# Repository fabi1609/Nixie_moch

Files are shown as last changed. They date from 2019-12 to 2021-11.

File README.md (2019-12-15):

# Nixie_moch

You are not permitted to use this design commercially.
This work is licensed under a Attribution-NonCommercial-ShareAlike 4.0 International (CC BY-NC-SA 4.0) License.



## Description

This is a tiny IN-12 Nixie clock based on STM32. Every SMD component is placed on the bottom side of the PCB. Hardware works with 5 V USB power supply. Boost converter is regulated and driven by STM32.
This project is in beta phase.

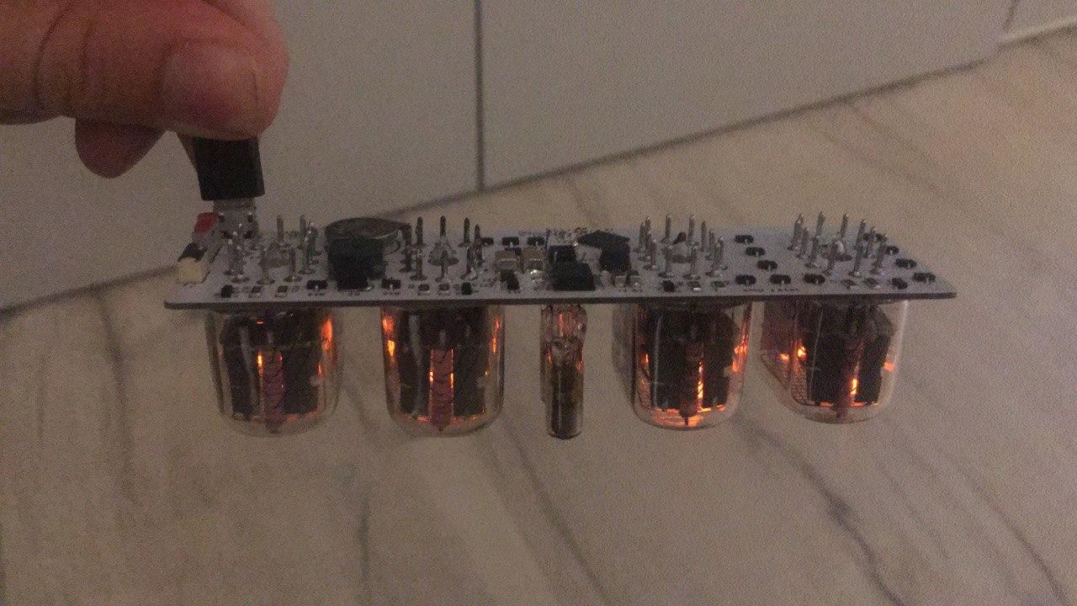
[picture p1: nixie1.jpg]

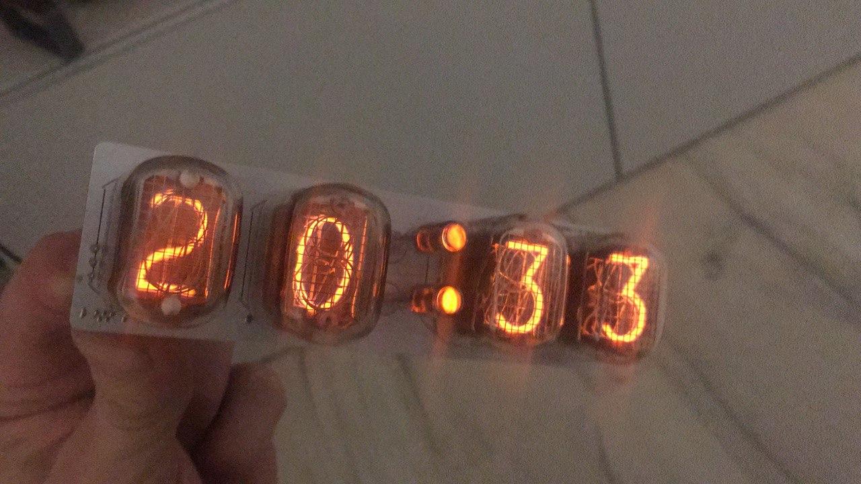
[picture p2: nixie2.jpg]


## TODO: Write explanation

You are not permitted to use this design commercially.
This work is licensed under a Attribution-NonCommercial-ShareAlike 4.0 International (CC BY-NC-SA 4.0) License.



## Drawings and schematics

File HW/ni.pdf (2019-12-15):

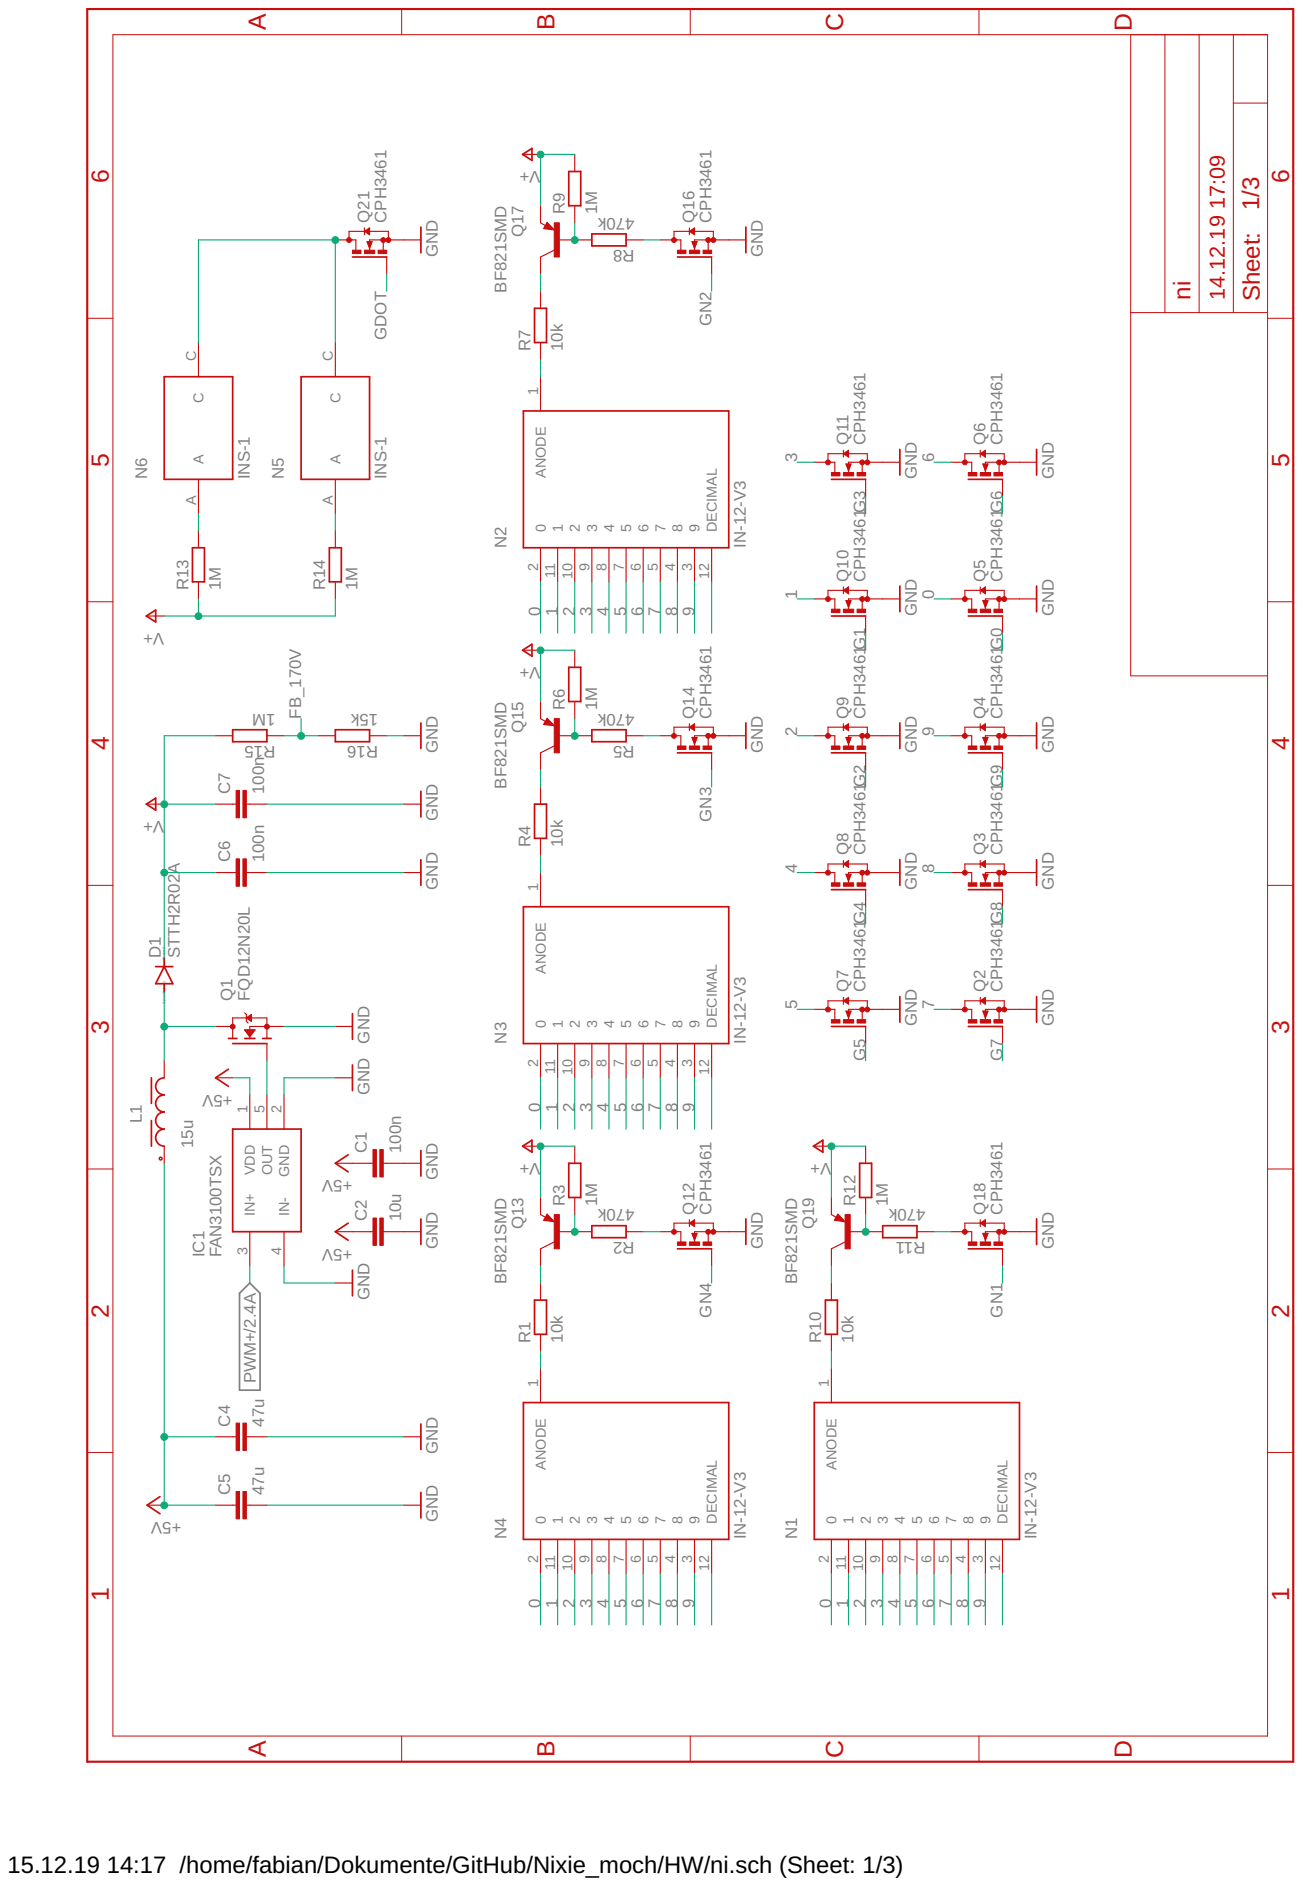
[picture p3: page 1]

GND GND GND GND GND

15.12.19 14:17 /home/fabian/Dokumente/GitHub/Nixie_moch/HW/ni.sch (Sheet: 1/3)

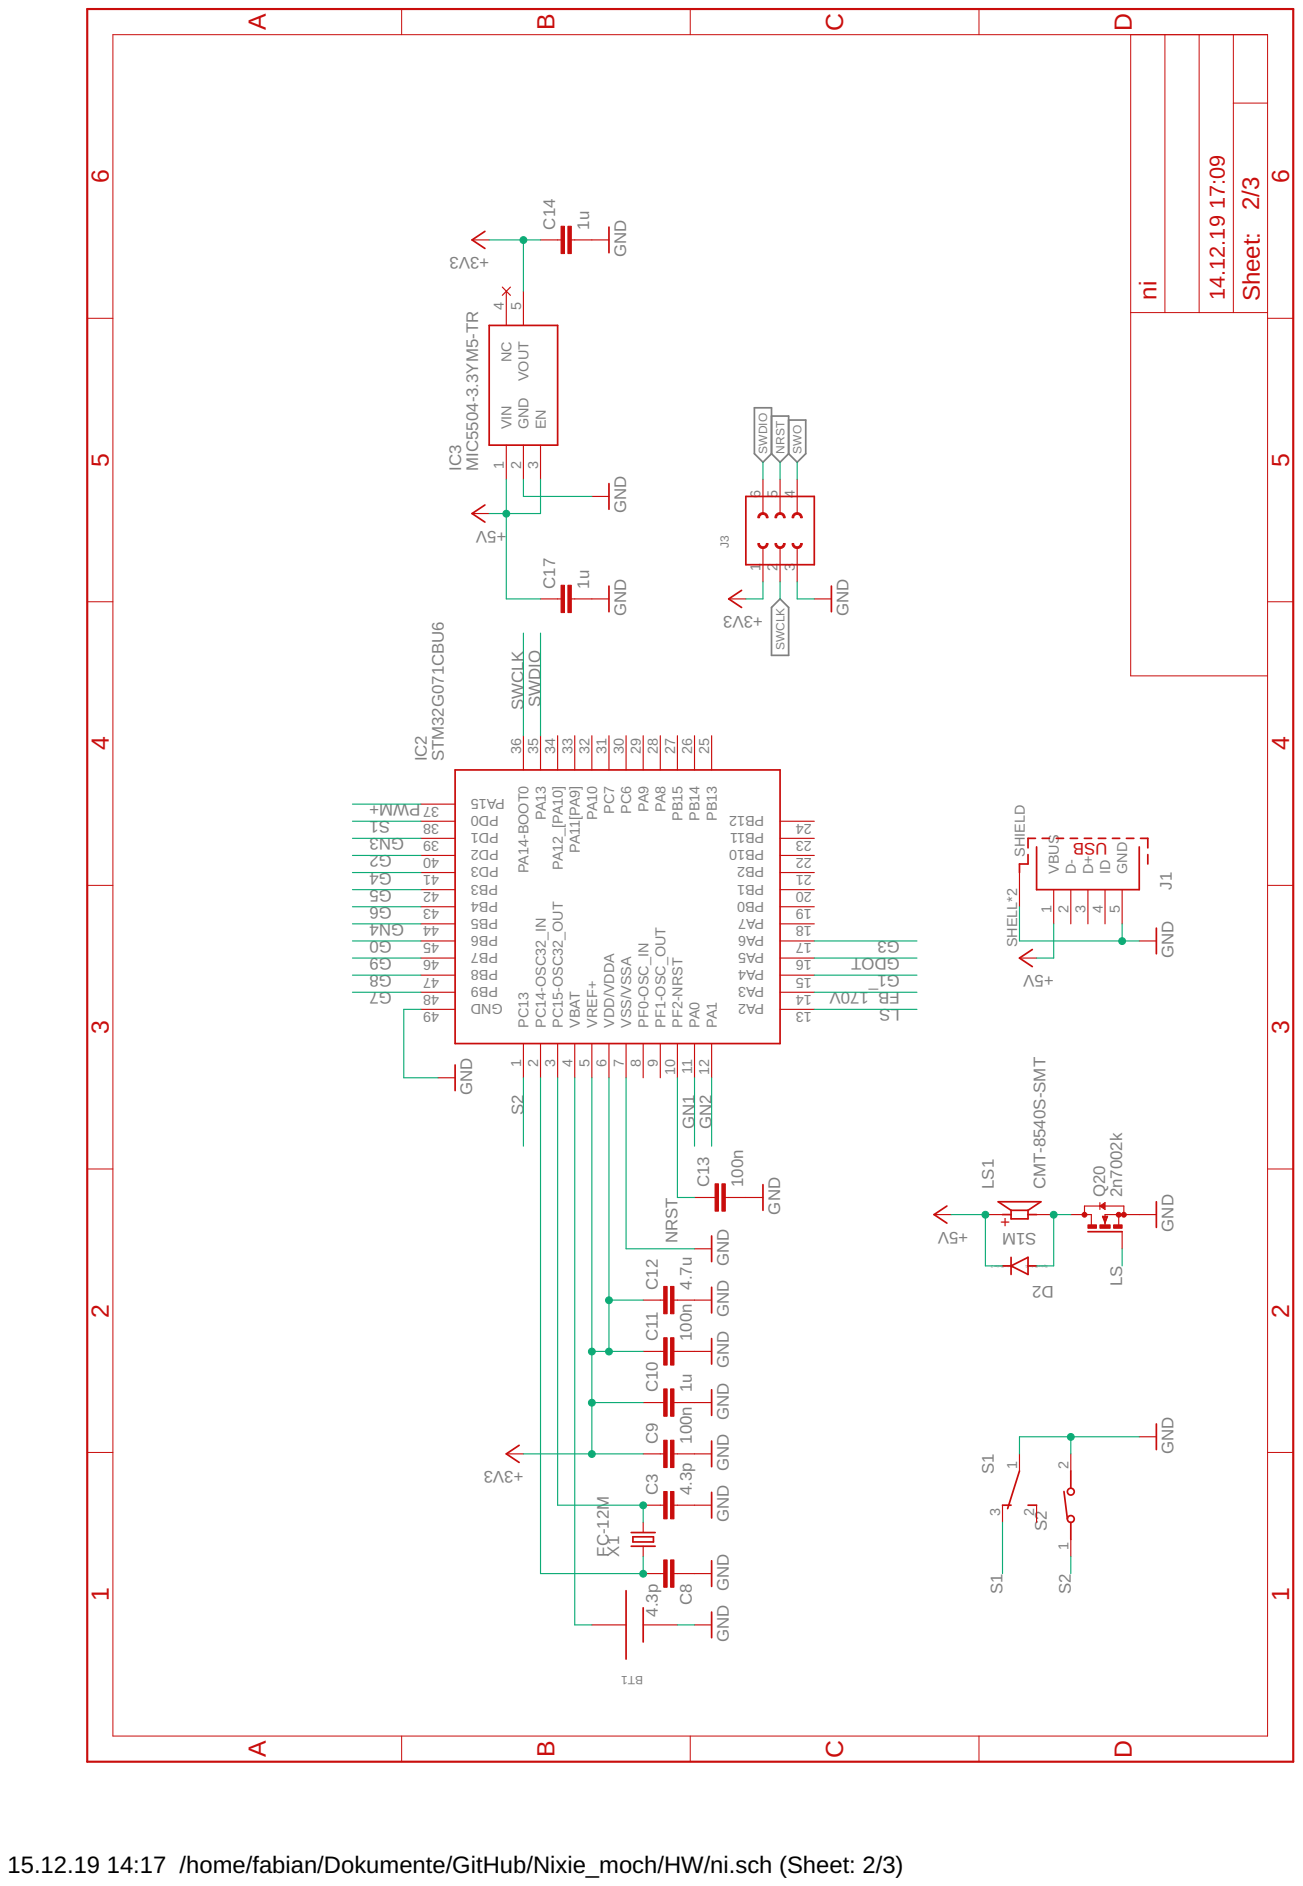
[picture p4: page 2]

15.12.19 14:17 /home/fabian/Dokumente/GitHub/Nixie_moch/HW/ni.sch (Sheet: 2/3)

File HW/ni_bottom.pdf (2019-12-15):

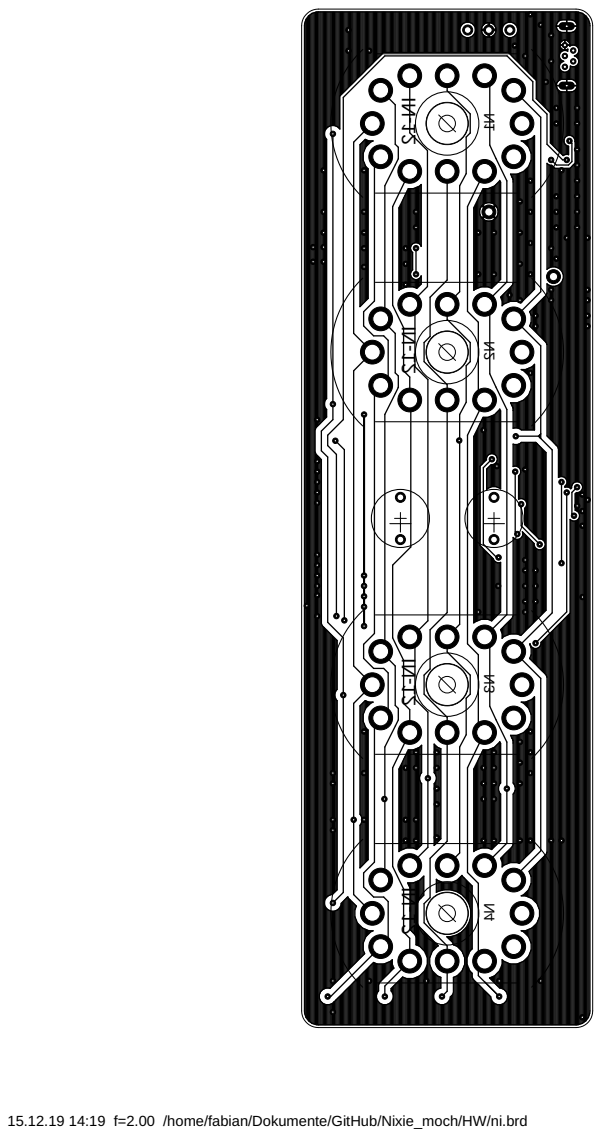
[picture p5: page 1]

15.12.19 14:19 f=2.00 /home/fabian/Dokumente/GitHub/Nixie_moch/HW/ni.brd

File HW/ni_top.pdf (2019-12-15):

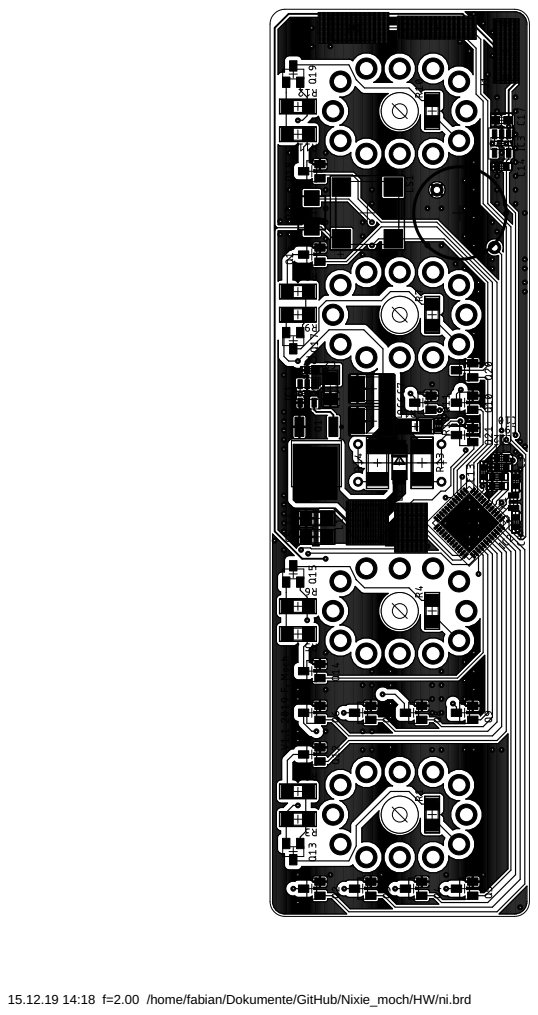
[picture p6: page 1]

15.12.19 14:18 f=2.00 /home/fabian/Dokumente/GitHub/Nixie_moch/HW/ni.brd

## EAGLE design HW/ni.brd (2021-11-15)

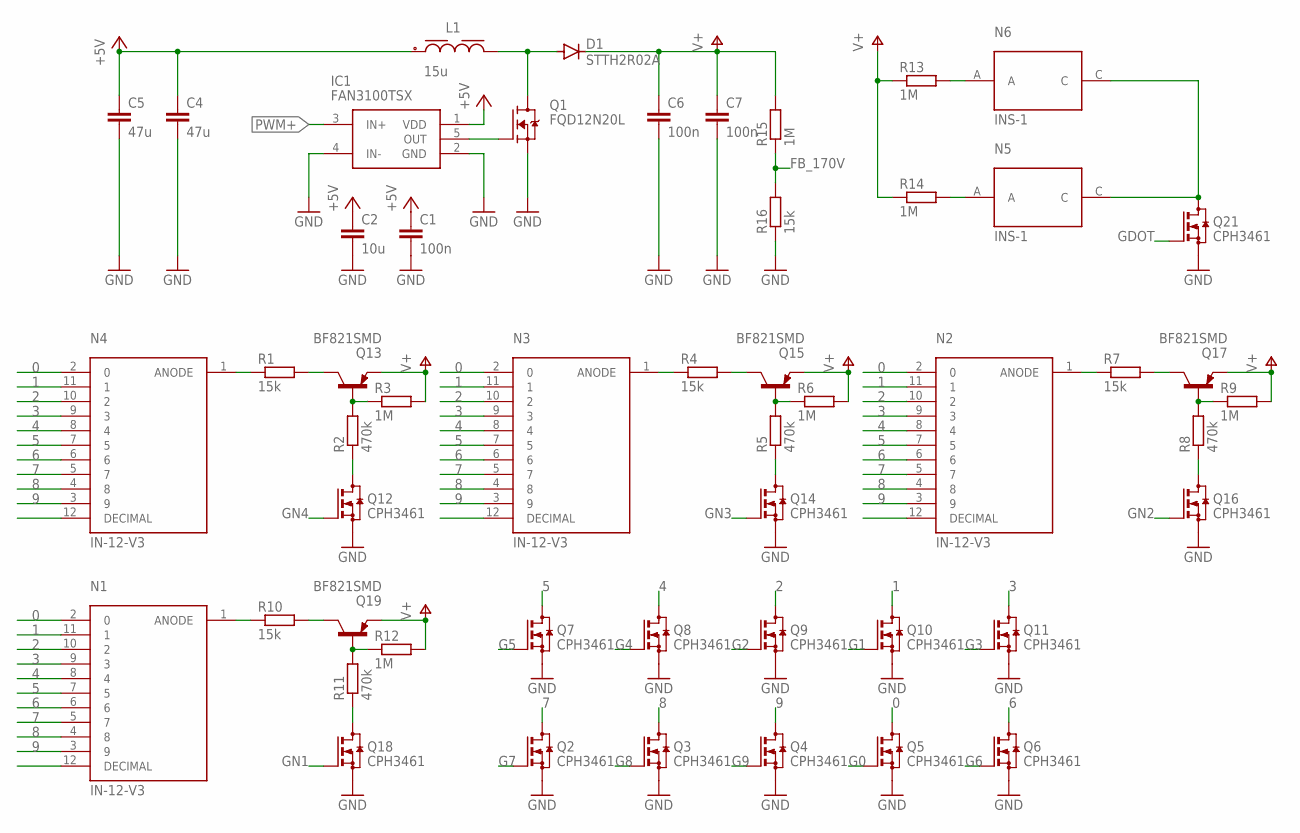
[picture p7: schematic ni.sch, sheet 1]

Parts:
C1: 100n; C0402
C2: 10u; C1206
C4, C5: 47u; C1206
C6, C7: 100n; C1812
D1: STTH2R02A; DO214AC
IC1: FAN3100TSX; SOT95P280X145-5N
L1: 15u; WE-LQS_5040
N1, N2, N3, N4: IN-12-V3; IN-12
N5, N6: INS-1
Q1: FQD12N20L; TO229P990X240-3N
Q2, Q3, Q4, Q5, Q6, Q7, Q8, Q9, Q10, Q11, Q12, Q14, Q16, Q18, Q21: CPH3461; SOT23
Q13, Q15, Q17, Q19: BF821SMD; SOT23-BEC
R1, R4, R7, R10: 15k; R1206
R2, R5, R8, R11: 470k; R1206
R3, R6, R9, R12, R15: 1M; R1206
R13, R14: 1M; R2010
R16: 15k; R0402

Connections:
0: N1.2 (0), N2.2 (0), N3.2 (0), N4.2 (0), Q5.3 (D)
1: N1.11 (1), N2.11 (1), N3.11 (1), N4.11 (1), Q10.3 (D)
2: N1.10 (2), N2.10 (2), N3.10 (2), N4.10 (2), Q9.3 (D)
3: N1.9 (3), N2.9 (3), N3.9 (3), N4.9 (3), Q11.3 (D)
4: N1.8 (4), N2.8 (4), N3.8 (4), N4.8 (4), Q8.3 (D)
5: N1.7 (5), N2.7 (5), N3.7 (5), N4.7 (5), Q7.3 (D)
6: N1.6, N2.6, N3.6, N4.6, Q6.3 (D)
7: N1.5 (7), N2.5 (7), N3.5 (7), N4.5 (7), Q2.3 (D)
8: N1.4 (8), N2.4 (8), N3.4 (8), N4.4 (8), Q3.3 (D)
9: N1.3 (9), N2.3 (9), N3.3 (9), N4.3 (9), Q4.3 (D)
+5V: C1.1, C2.1, C4.1, C5.1, IC1.1 (VDD), L1.1; also elsewhere on the board
FB_170V: R15.1, R16.2; also elsewhere on the board
G0: Q5.1 (G); also elsewhere on the board
G1: Q10.1 (G); also elsewhere on the board
G2: Q9.1 (G); also elsewhere on the board
G3: Q11.1 (G); also elsewhere on the board
G4: Q8.1 (G); also elsewhere on the board
G5: Q7.1 (G); also elsewhere on the board
G6: Q6.1 (G); also elsewhere on the board
G7: Q2.1 (G); also elsewhere on the board
G8: Q3.1 (G); also elsewhere on the board
G9: Q4.1 (G); also elsewhere on the board
GDOT: Q21.1 (G); also elsewhere on the board
GN1: Q18.1 (G); also elsewhere on the board
GN2: Q16.1 (G); also elsewhere on the board
GN3: Q14.1 (G); also elsewhere on the board
GN4: Q12.1 (G); also elsewhere on the board
GND: C1.2, C2.2, C4.2, C5.2, C6.2, C7.2, IC1.2 (GND), IC1.4 (IN-), Q1.2 (S), Q2.2 (S), Q3.2 (S), Q4.2 (S), Q5.2 (S), Q6.2 (S), Q7.2 (S), Q8.2 (S), Q9.2 (S), Q10.2 (S), Q11.2 (S), Q12.2 (S), Q14.2 (S), Q16.2 (S), Q18.2 (S), Q21.2 (S), R16.1; also elsewhere on the board
unnamed: D1.A, L1.2, Q1.3 (D)
unnamed: IC1.5 (OUT), Q1.1 (G)
unnamed: N3.1 (ANODE), R4.1
unnamed: N4.1 (ANODE), R1.1
unnamed: Q13.C, R1.2
unnamed: Q13.B, R2.2, R3.1
unnamed: Q12.3 (D), R2.1
unnamed: Q15.C, R4.2
unnamed: N5.C, N6.C, Q21.3 (D)
unnamed: N6.A, R13.2
unnamed: Q15.B, R5.2, R6.1
unnamed: Q14.3 (D), R5.1
unnamed: N2.1 (ANODE), R7.1
unnamed: Q17.C, R7.2
unnamed: Q17.B, R8.2, R9.1
unnamed: Q16.3 (D), R8.1
unnamed: N1.1 (ANODE), R10.1
unnamed: Q19.C, R10.2
unnamed: Q19.B, R11.2, R12.1
unnamed: Q18.3 (D), R11.1
unnamed: N5.A, R14.2
PWM+: IC1.3 (IN+); also elsewhere on the board
V+: C6.1, C7.1, D1.C, Q13.E, Q15.E, Q17.E, Q19.E, R3.2, R6.2, R9.2, R12.2, R13.1, R14.1, R15.2

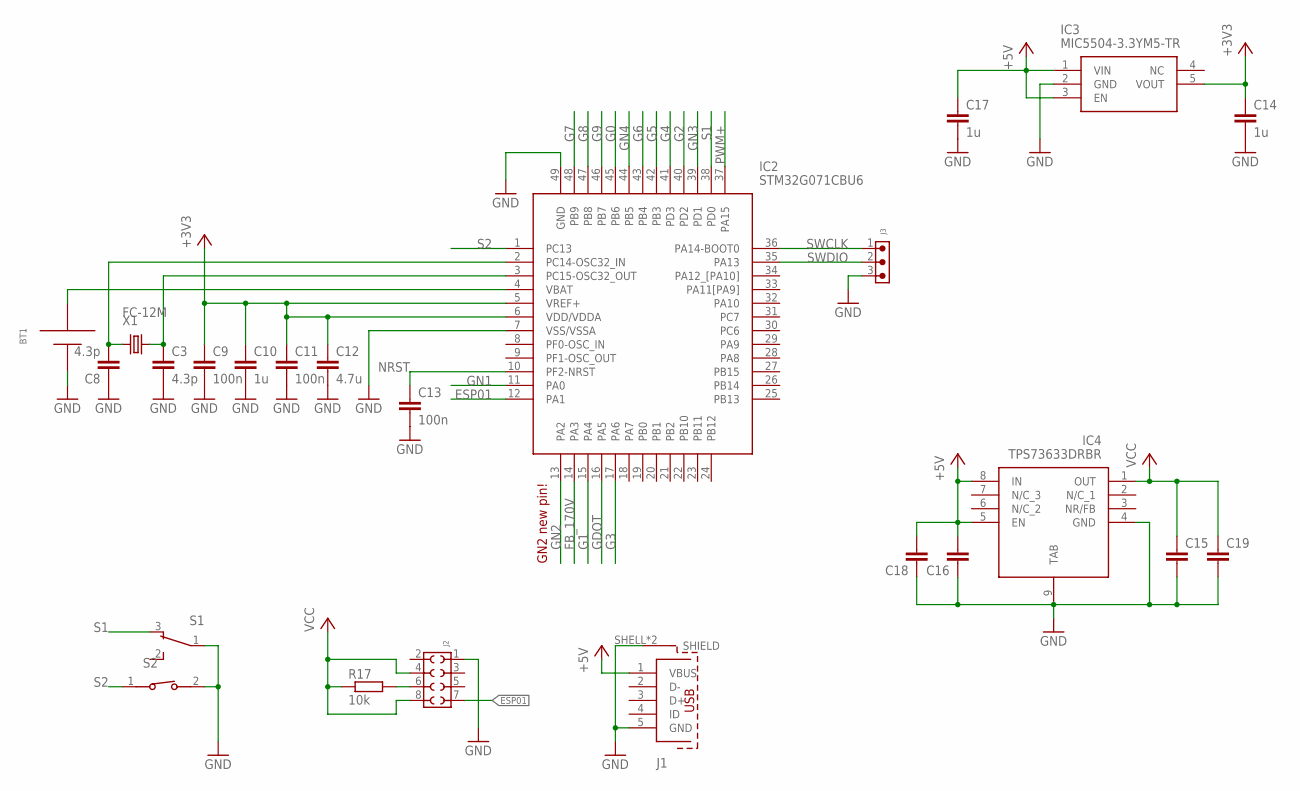
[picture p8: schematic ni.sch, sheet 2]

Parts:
BT1: CR1225FH-LF
C3, C8: 4.3p; C0402
C9, C11, C13: 100n; C0402
C10, C14: 1u; C0402
C12: 4.7u; C0402
C15, C16: C-EUC1206; C1206
C17: 1u; C0603
C18, C19: C-EUC0603; C0603
IC2: STM32G071CBU6; QFN50P700X700X60-49N
IC3: MIC5504-3.3YM5-TR; SOT95P280X145-5N
IC4: TPS73633DRBR; SON65P300X300X100-9N
J1: 614105150721
J2: 6100XX21821_61000821821; 61000821821
J3: OWN_3PIN; OWN-3PIN
R17: 10k; R0402
S1: 450301014042
S2: 434121050816
X1: FC-12M

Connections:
+3V3: C9.1, C10.1, C11.1, C12.1, C14.1, IC2.5 (VREF+), IC2.6 (VDD/VDDA), IC3.5 (VOUT)
+5V: C16.2, C17.1, C18.2, IC3.1 (VIN), IC3.3 (EN), IC4.5 (EN), IC4.8 (IN), J1.1 (VBUS); also elsewhere on the board
ESP01: IC2.12 (PA1), J2.7
FB_170V: IC2.14 (PA3); also elsewhere on the board
G0: IC2.45 (PB6); also elsewhere on the board
G1: IC2.15 (PA4); also elsewhere on the board
G2: IC2.40 (PD2); also elsewhere on the board
G3: IC2.17 (PA6); also elsewhere on the board
G4: IC2.41 (PD3); also elsewhere on the board
G5: IC2.42 (PB3); also elsewhere on the board
G6: IC2.43 (PB4); also elsewhere on the board
G7: IC2.48 (PB9); also elsewhere on the board
G8: IC2.47 (PB8); also elsewhere on the board
G9: IC2.46 (PB7); also elsewhere on the board
GDOT: IC2.16 (PA5); also elsewhere on the board
GN1: IC2.11 (PA0); also elsewhere on the board
GN2: IC2.13 (PA2); also elsewhere on the board
GN3: IC2.39 (PD1); also elsewhere on the board
GN4: IC2.44 (PB5); also elsewhere on the board
GND: BT1.-, C3.2, C8.1, C9.2, C10.2, C11.2, C12.2, C13.2, C14.2, C15.2, C16.1, C17.2, C18.1, C19.2, IC2.7 (VSS/VSSA), IC2.49 (GND), IC3.2 (GND), IC4.4 (GND), IC4.9 (TAB), J1.5 (GND), J1.SHELL (SHIELD), J1.SHELL1 (SHIELD), J2.1, J3.3, S1.1, S2.2; also elsewhere on the board
unnamed: J2.6, R17.2
unnamed: BT1.+, IC2.4 (VBAT)
unnamed: C3.1, IC2.3 (PC15-OSC32_OUT), X1.2
unnamed: C8.2, IC2.2 (PC14-OSC32_IN), X1.1
NRST: C13.1, IC2.10 (PF2-NRST)
PWM+: IC2.37 (PA15); also elsewhere on the board
S1: IC2.38 (PD0), S1.3
S2: IC2.1 (PC13), S2.1
SWCLK: IC2.36 (PA14-BOOT0), J3.1
SWDIO: IC2.35 (PA13), J3.2
VCC: C15.1, C19.1, IC4.1 (OUT), J2.4, J2.8, R17.1

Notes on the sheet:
GN2 new pin!

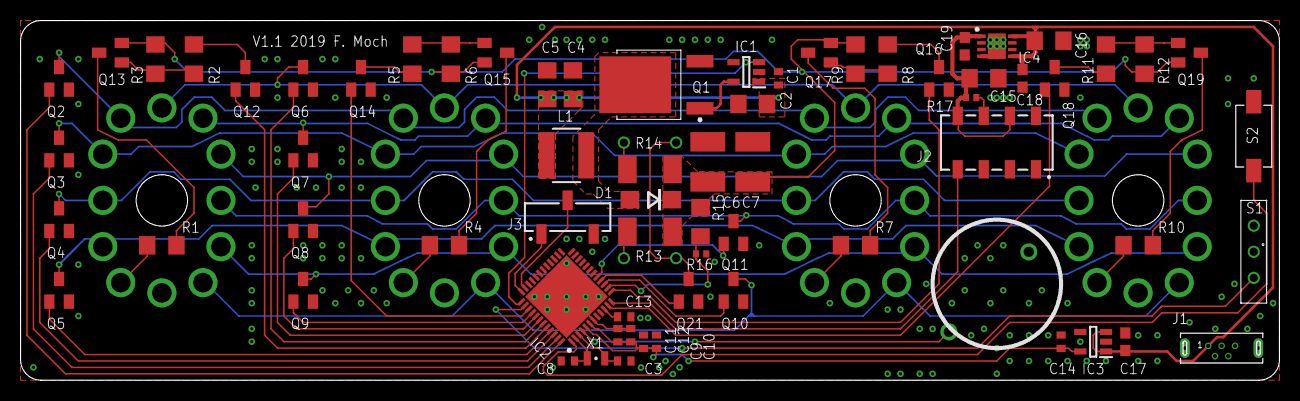
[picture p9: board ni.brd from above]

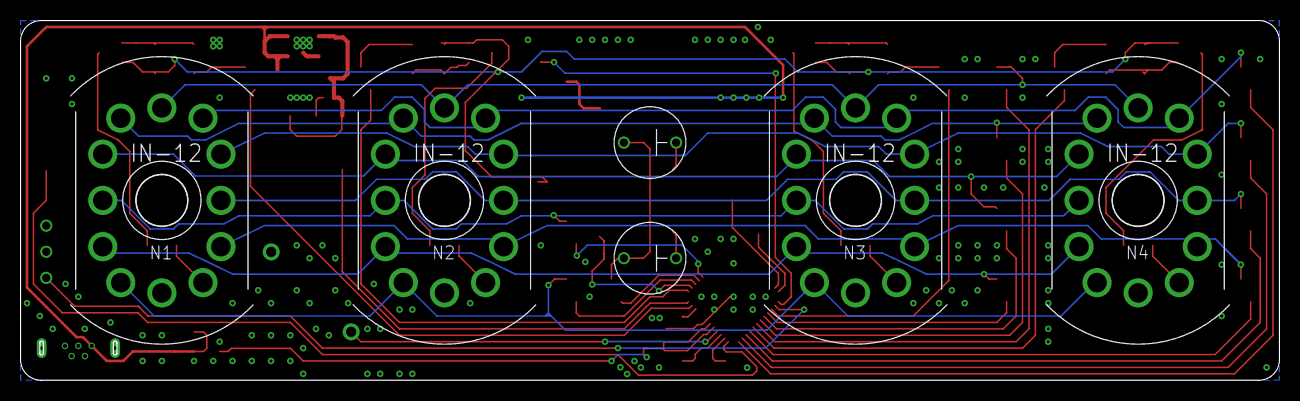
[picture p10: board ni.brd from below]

Board: 2 copper layers, 122.5 x 35.0 mm, 75 parts (6 on the bottom side), 63 nets.

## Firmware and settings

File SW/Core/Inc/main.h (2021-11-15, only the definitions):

#define S2_Pin LL_GPIO_PIN_13
#define S2_GPIO_Port GPIOC
#define NRST_Pin LL_GPIO_PIN_2
#define NRST_GPIO_Port GPIOF
#define GN1_Pin LL_GPIO_PIN_0
#define GN1_GPIO_Port GPIOA
#define ESP01_Pin LL_GPIO_PIN_1
#define ESP01_GPIO_Port GPIOA
#define ESP01_EXTI_IRQn EXTI0_1_IRQn
#define GN2_Pin LL_GPIO_PIN_2
#define GN2_GPIO_Port GPIOA
#define FB_170V_Pin LL_GPIO_PIN_3
#define FB_170V_GPIO_Port GPIOA
#define G1_Pin LL_GPIO_PIN_4
#define G1_GPIO_Port GPIOA
#define GDOT_Pin LL_GPIO_PIN_5
#define GDOT_GPIO_Port GPIOA
#define G3_Pin LL_GPIO_PIN_6
#define G3_GPIO_Port GPIOA
#define S1_Pin LL_GPIO_PIN_0
#define S1_GPIO_Port GPIOD
#define GN3_Pin LL_GPIO_PIN_1
#define GN3_GPIO_Port GPIOD
#define G2_Pin LL_GPIO_PIN_2
#define G2_GPIO_Port GPIOD
#define G4_Pin LL_GPIO_PIN_3
#define G4_GPIO_Port GPIOD
#define G5_Pin LL_GPIO_PIN_3
#define G5_GPIO_Port GPIOB
#define G6_Pin LL_GPIO_PIN_4
#define G6_GPIO_Port GPIOB
#define GN4_Pin LL_GPIO_PIN_5
#define GN4_GPIO_Port GPIOB
#define G0_Pin LL_GPIO_PIN_6
#define G0_GPIO_Port GPIOB
#define G9_Pin LL_GPIO_PIN_7
#define G9_GPIO_Port GPIOB
#define G8_Pin LL_GPIO_PIN_8
#define G8_GPIO_Port GPIOB
#define G7_Pin LL_GPIO_PIN_9
#define G7_GPIO_Port GPIOB

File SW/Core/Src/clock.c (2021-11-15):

/*
 * clock.c
 *
 *  Created on: Nov 13, 2019
 *      Author: Fabian
 */

#include "clock.h"
#include "nixie.h"
#include "settings.h"
#include "gpio.h"
#include "tim.h"
#include "rtc.h"

RTC_TimeTypeDef sTime1;
RTC_DateTypeDef sDate1;

volatile uint8_t ESP01_state = CL_STATE_INIT;
volatile uint8_t ESP01_h;
volatile uint8_t ESP01_m;
volatile uint8_t ESP01_s;

//Called every second
void HAL_RTC_AlarmAEventCallback(RTC_HandleTypeDef *hrtc)
{
	HAL_RTC_GetTime(hrtc, &sTime1, RTC_FORMAT_BIN); // Get Time
	HAL_RTC_GetDate(hrtc, &sDate1, RTC_FORMAT_BIN); // Get Date

	//Set clock
	if(!HAL_GPIO_ReadPin(S2_GPIO_Port, S2_Pin))
	{
		if(HAL_GPIO_ReadPin(S1_GPIO_Port, S1_Pin))
		{
			sTime1.SecondFraction = 0;
			sTime1.Seconds = 0;
			if(sTime1.Minutes < 59)
				sTime1.Minutes = sTime1.Minutes + 1;
			else
				sTime1.Minutes = 0;
		}
		else
		{
			if(sTime1.Hours < 23)
				sTime1.Hours = sTime1.Hours + 1;
			else
				sTime1.Hours = 0;
		}
		HAL_RTC_SetTime(hrtc, &sTime1, RTC_FORMAT_BIN);
		HAL_RTC_SetDate(hrtc, &sDate1, RTC_FORMAT_BIN);
	}

	//Display Time
	nixie_set_time(sTime1.Hours, sTime1.Minutes, sTime1.Seconds);

	//Scheduled reboot
	if(sTime1.Hours == REBOOT_H && sTime1.Minutes == REBOOT_M && sTime1.Seconds == 0)
	{
		HAL_NVIC_SystemReset();
	}
}

void ESP01_init()
{
	HAL_TIM_Base_Start(&htim17);

}

//get time from ESP01 Board
//trigger on falling edge
void OWN_LL_EXTI()
{
	switch(ESP01_state)
	{
	case CL_STATE_INIT:
		ESP01_h = 0;
		ESP01_m = 0;
		ESP01_s = 0;
		__HAL_TIM_SetCounter(&htim17, 0); //TIM17 counts with 1000 Hz
		ESP01_state = CL_STATE_READ_START;
		break;
	case CL_STATE_READ_START:
		if(__HAL_TIM_GET_COUNTER(&htim17) > 22 && __HAL_TIM_GET_COUNTER(&htim17) < 28)
		{
			ESP01_state = CL_STATE_READ_H; //read h when pause 25 ms was send.
			__HAL_TIM_SetCounter(&htim17, 0);
		}
		else if(__HAL_TIM_GET_COUNTER(&htim17) > 12 && __HAL_TIM_GET_COUNTER(&htim17) < 18)
		{
			ESP01_state = CL_STATE_READ_M; //read m when pause 15 ms was send.
			__HAL_TIM_SetCounter(&htim17, 0);
		}
		else if(__HAL_TIM_GET_COUNTER(&htim17) > 2 && __HAL_TIM_GET_COUNTER(&htim17) < 8)
		{
			ESP01_state = CL_STATE_READ_S; //read s when pause 5 ms was send.
			__HAL_TIM_SetCounter(&htim17, 0);
		}
		else
			HAL_NVIC_SystemReset();
		break;
	case CL_STATE_READ_H: //read h
		//read h finished when pause 25 ms was send and value plausible.
		if(ESP01_h < 25 && __HAL_TIM_GET_COUNTER(&htim17) > 22 && __HAL_TIM_GET_COUNTER(&htim17) < 28)
		{
			sTime1.Hours = ESP01_h - 1;
			HAL_RTC_SetTime(&hrtc, &sTime1, RTC_FORMAT_BIN);
			HAL_RTC_SetDate(&hrtc, &sDate1, RTC_FORMAT_BIN);
			ESP01_state = CL_STATE_INIT;
		}
		else if(ESP01_h < 25 && __HAL_TIM_GET_COUNTER(&htim17) <= 22)
		{
			ESP01_h++;
			__HAL_TIM_SetCounter(&htim17, 0);
		}
		else
		{
			// Error
			HAL_NVIC_SystemReset();
		}
		break;
	case CL_STATE_READ_M: //read m
		//read m finished when pause 15 ms was send and value plausible.
		if(ESP01_m < 61 && __HAL_TIM_GET_COUNTER(&htim17) > 12 && __HAL_TIM_GET_COUNTER(&htim17) < 18)
		{
			sTime1.Minutes = ESP01_m - 1;
			HAL_RTC_SetTime(&hrtc, &sTime1, RTC_FORMAT_BIN);
			HAL_RTC_SetDate(&hrtc, &sDate1, RTC_FORMAT_BIN);
			ESP01_state = CL_STATE_INIT;
		}
		else if(ESP01_m < 61 && __HAL_TIM_GET_COUNTER(&htim17) <= 12)
		{
			ESP01_m++;
			__HAL_TIM_SetCounter(&htim17, 0);
		}
		else
		{
			// Error
			HAL_NVIC_SystemReset();
		}
		break;
	case CL_STATE_READ_S: //read s
		//read s finished when pause 5 ms was send and value plausible.
		if(ESP01_s < 61 && __HAL_TIM_GET_COUNTER(&htim17) > 2 && __HAL_TIM_GET_COUNTER(&htim17) < 8)
		{
			sTime1.Seconds = ESP01_s - 1;
			sTime1.SecondFraction = 1;
			HAL_RTC_SetTime(&hrtc, &sTime1, RTC_FORMAT_BIN);
			HAL_RTC_SetDate(&hrtc, &sDate1, RTC_FORMAT_BIN);
			ESP01_state = CL_STATE_INIT;
		}
		else if(ESP01_s < 61 && __HAL_TIM_GET_COUNTER(&htim17) <= 2) //timeout
		{
			ESP01_s++;
			__HAL_TIM_SetCounter(&htim17, 0);
		}
		else
		{
			// Error
			HAL_NVIC_SystemReset();
		}
		break;
	}
}

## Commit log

2019-10-22 Neu sortiert
    [ni.brd, ni.sch]
2019-10-28 timers configuration
2019-10-31 HW_values added
    [ni.brd, ni.sch]
2019-11-08 CPU to 64 MHz and one shot timer setting
2019-11-08 activatet pullups and activatet forgotten interrupt
2019-11-12 Set target voltage
2019-11-13 Nixie working; Comp start; Faster boost start; Multiplex error fixed
    [nixie.c, nixie.ioc]
2019-11-14 HW V1.1 fixed 3.3V supply
    [ni.brd, ni.sch]
2019-11-15 V1.1 fixed nixie footprint
    [ni.brd, ni.sch]
2019-11-16 changed button logic and set voltage to 145V
2019-11-22 V1.1 revertet to old nixie footprint for socket mounting
    [ni.brd, ni.sch]
2020-01-29 WIFI added
    [ni.brd, ni.sch]
2020-02-15 clock.h, clock.c und main.c aktualisiert
2020-03-09 ni.brd, ni.sch und 13 weitere dateien aktualisiert...
    [ni.brd, ni.sch]

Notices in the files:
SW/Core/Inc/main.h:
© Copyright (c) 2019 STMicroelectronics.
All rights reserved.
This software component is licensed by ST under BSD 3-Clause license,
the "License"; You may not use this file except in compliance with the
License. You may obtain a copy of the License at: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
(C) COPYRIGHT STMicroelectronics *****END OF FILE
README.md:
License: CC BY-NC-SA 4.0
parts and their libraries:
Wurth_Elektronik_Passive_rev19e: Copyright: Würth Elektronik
